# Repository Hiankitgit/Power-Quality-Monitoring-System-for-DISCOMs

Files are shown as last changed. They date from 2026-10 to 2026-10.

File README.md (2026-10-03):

# Power Quality Monitoring System for DISCOMs

   

## 📌 Overview
A low-cost, embedded diagnostic node designed for electricity distribution networks (DISCOMs). This system is engineered to detect sub-threshold power quality anomalies that are typically invisible to conventional protection devices. 

The hardware acts as a unified motherboard, integrating microcontrollers, analog voltage sensing, and industrial RS-485 communication into a single robust node.

## 🔌 Hardware Architecture
The custom PCB functions as a docking station utilizing pre-built modules and discrete through-hole components:
*   **Microcontrollers:** Arduino Uno & STM32 Blue Pill
*   **Voltage Sensing:** ZMPT101B AC voltage transformer module
*   **Communication:** MAX485 (TTL-to-RS485 transceiver) for node-level fault reporting
*   **Safety Infrastructure:** 220V AC mains are wired directly into the ZMPT module terminals, keeping high-voltage traces entirely isolated from the custom 5V logic board.

## 🛠️ PCB Design & Fabrication
Designed entirely in **KiCad**, the board layout was heavily optimized for DIY in-house manufacturing.
*   **Clearances & Traces:** Passed stringent DRC with 0.2mm minimum clearance. Main 5V and GND power rails are thickened (0.8mm) to prevent voltage drops across the docked modules.
*   **Routing Logic:** Verified intermediate node routing (including daisy-chained parallel capacitors) with 45-degree smoothed traces to prevent acid traps.
*   **Fabrication Method:** Specifically routed to support the **toner transfer etching** method on a blank copper clad board. A 1:1 scale mirrored PDF and standard Gerber `.zip` are provided in the `/fabrication` directory.

## 🖼️ Board Previews

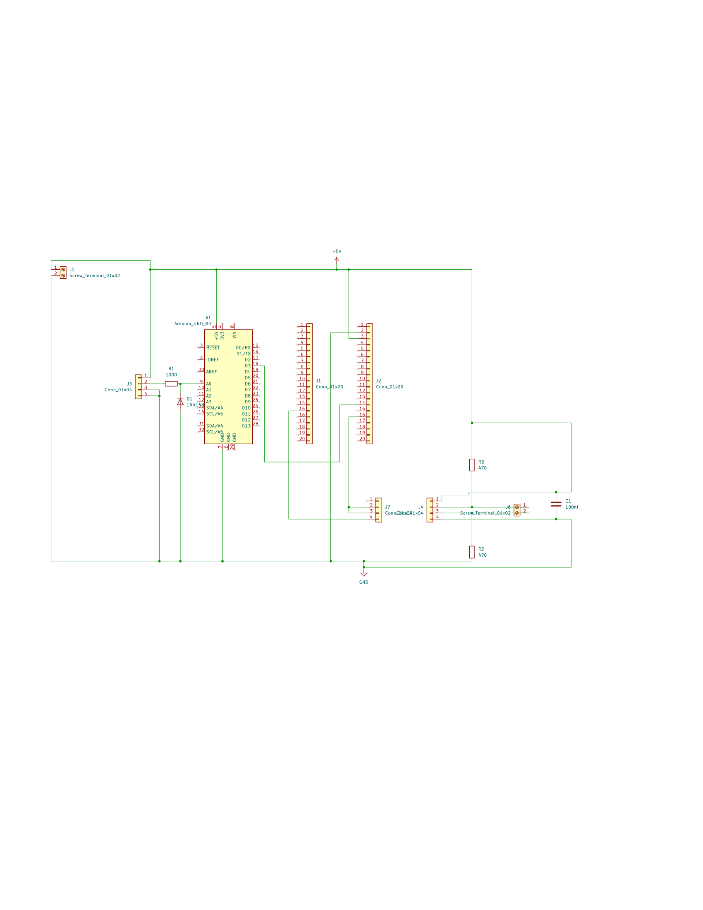
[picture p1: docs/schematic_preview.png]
Schematic Preview

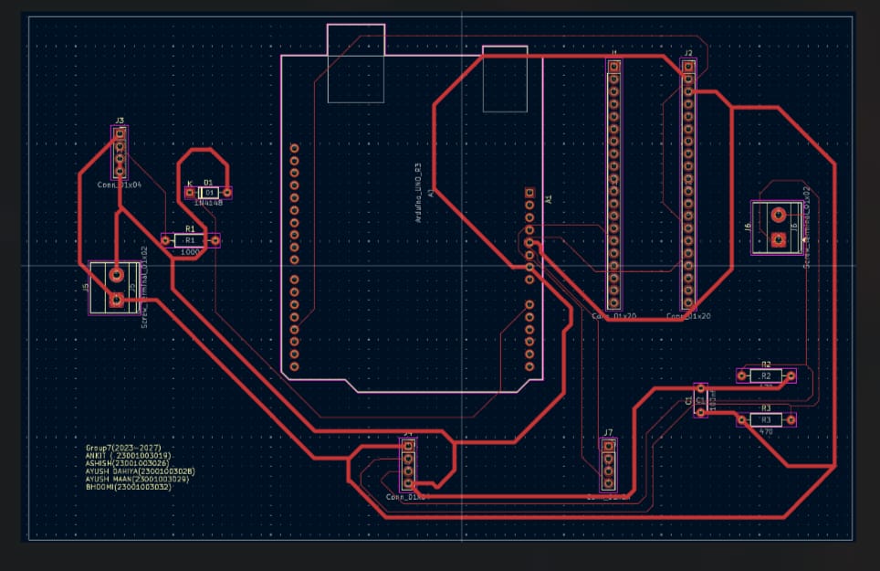
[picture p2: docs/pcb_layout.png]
PCB 2D Layout


# 💻 Firmware: Power Quality Monitoring Node

⚠️ **Status: Work In Progress (Fine-Tuning Phase)**

This directory contains the source code for the Arduino Uno and STM32 microcontrollers. 

### Current Development Focus
The baseline hardware communication is established, and we are actively calibrating the embedded signal processing algorithms. 
Current tasks include:
* Fine-tuning the ZMPT101B analog-to-digital (ADC) sampling windows.
* Implementing isolation and classification logic for 4 distinct power fault types.
* Formatting the RS-485 serial packet structure for reliable data transmission to DISCOMs.

Code will be updated regularly as the fault classification algorithms are finalized.

## 👥 Team & Credits
This system is being developed as an undergraduate academic group project by ECE Group 7 (2023–2027) under the supervision of Dr. Prachi Choudhary[cite: 8].

*   **Ankit** (23001003019) – Hardware Architecture & Lead PCB Design[cite: 3]
*   **Ashish** (23001003026)[cite: 3]
*   **Ayush Dahiya** (23001003028)[cite: 3]
*   **Ayush Maan** (23001003029)[cite: 3]
*   **Bhoomi** (23001003032)[cite: 3]

---
*Note: This repository contains the complete KiCad project files (`.kicad_pro`, `.kicad_sch`, `.kicad_pcb`), manufacturing drill/Gerber files, and firmware source code.*

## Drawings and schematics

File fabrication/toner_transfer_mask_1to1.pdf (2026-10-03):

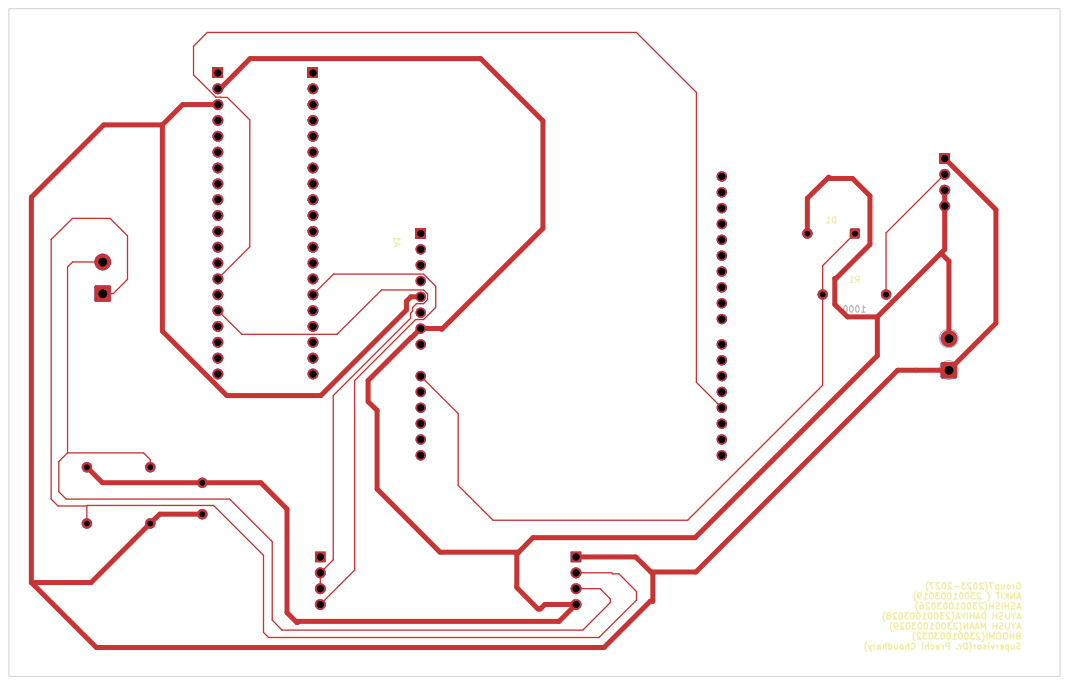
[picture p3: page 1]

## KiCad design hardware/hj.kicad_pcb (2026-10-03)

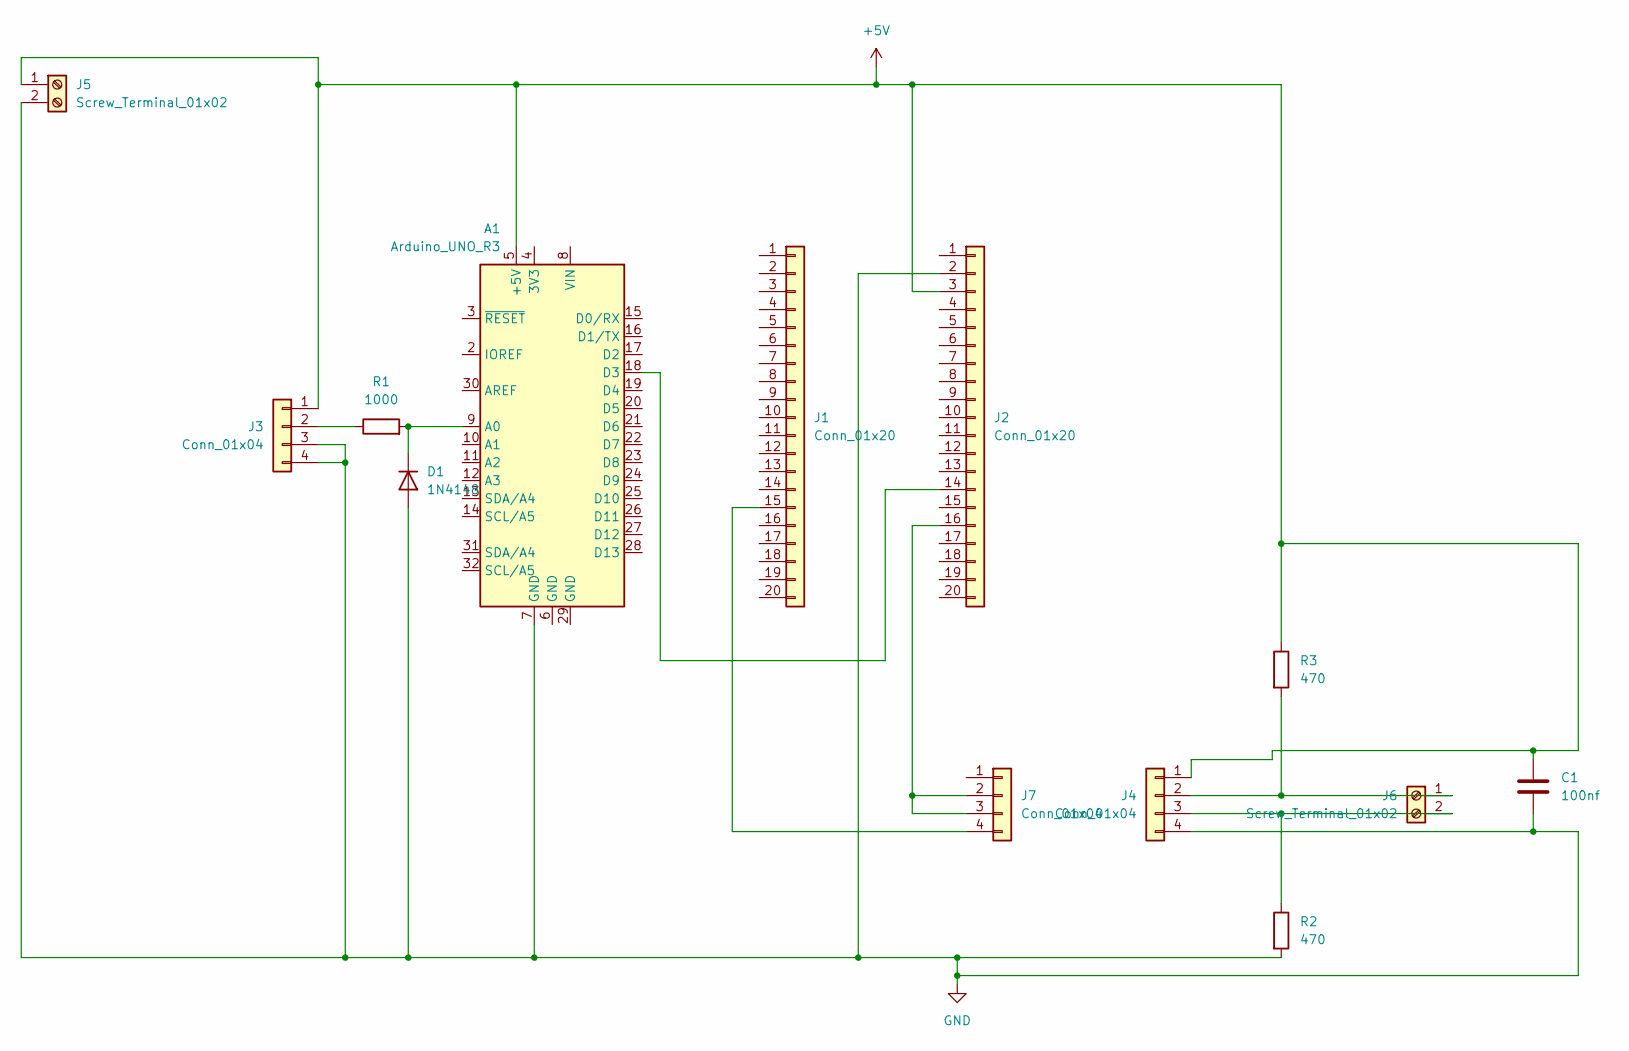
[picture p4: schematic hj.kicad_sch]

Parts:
A1: Arduino_UNO_R3
C1: 100nf; C_Disc_D5.0mm_W2.5mm_P5.00mm
D1: 1N4148; D_DO-35_SOD27_P7.62mm_Horizontal
J1, J2: Conn_01x20; PinSocket_1x20_P2.54mm_Vertical
J3, J4, J7: Conn_01x04; PinSocket_1x04_P2.54mm_Vertical
J5, J6: Screw_Terminal_01x02; TerminalBlock_Phoenix_MKDS-1,5-2-5.08_1x02_P5.08mm_Horizont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
R1: 1000; R_Axial_DIN0207_L6.3mm_D2.5mm_P10.16mm_Horizontal
R2, R3: 470; R_Axial_DIN0207_L6.3mm_D2.5mm_P10.16mm_Horizontal

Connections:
+5V: A1.5 (+5V), C1.1, J2.3, J3.1, J4.1, J5.1, R3.1
GND: A1.7 (GND), C1.2, D1.2 (A), J2.2, J3.3, J3.4, J4.4, J5.2, R2.2
unnamed: A1.9 (A0), D1.1 (K), R1.2
unnamed: A1.18 (D3), J2.14
unnamed: J1.15, J7.4
unnamed: J2.16, J7.2, J7.3
unnamed: J3.2, R1.1
unnamed: J4.2, J6.1, R3.2
unnamed: J4.3, J6.2, R2.1

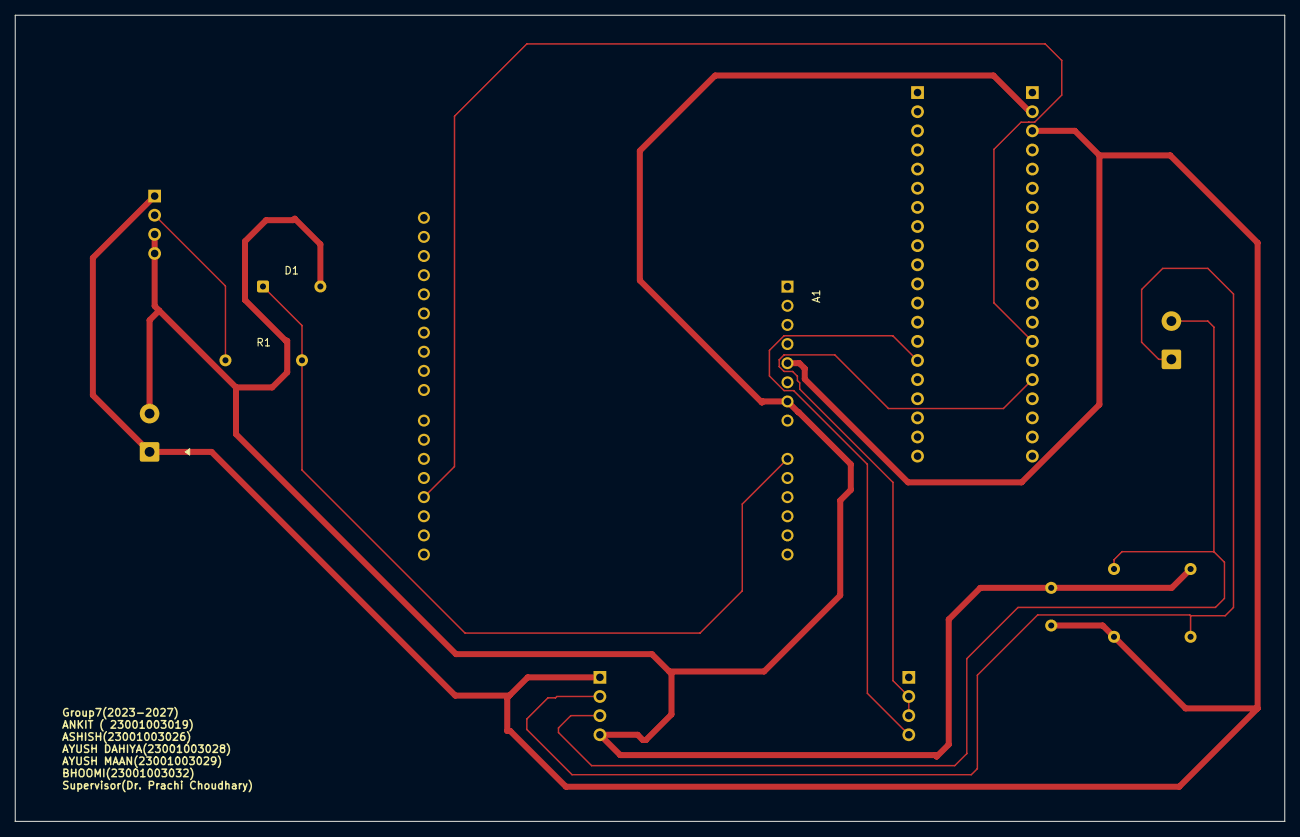
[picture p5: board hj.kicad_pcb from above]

Board: 2 copper layers, 168.5 x 107.0 mm, 13 parts (0 on the bottom side), 9 nets.

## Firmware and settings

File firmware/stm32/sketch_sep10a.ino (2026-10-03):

// ============================================================
//  POWER QUALITY MONITOR — STM32 Blue Pill Classifier
//  DCRUST BTech Project | Final Tuned Version (2V Sag Drop)
// ============================================================
#include <Arduino.h>

Uart SerialUno(PA10, PA9);      
Uart SerialRS485(PB11, PB10);   

#define RS485_DE_RE PA8

float SAG_V      = 0.0f;
float SWELL_V    = 0.0f;
float CREST_MAX  = 0.0f;
long  NOISE_MED  = 0;
long  NOISE_HIGH = 0;
const int ZC_NORMAL = 2;
const int MAX_PER_CLASS = 5;

// --- Auto-Calibration Variables ---
bool isCalibrated = false;
int  calibCount = 0;
float sumRms = 0;
float sumCf = 0;
long  sumNoise = 0;
const int REQUIRED_CALIB_SAMPLES = 100; 

int tappingCounter = 0; 

unsigned long lastHeartbeatMs = 0;
const unsigned long HEARTBEAT_MS = 10000UL;

struct Features {
  float rms; float peak; int zeroCross; long noiseEnergy; float crestFactor;
};

struct Scores {
  int tap; int loose; int overload; int degrade;
};

static uint8_t xorChecksum(const char* s) {
  uint8_t crc = 0;
  while (*s) crc ^= (uint8_t)(*s++);
  return crc;
}

static bool parsePacket(const char* raw, Features* f) {
  if (!raw || raw[0] != 'F' || raw[1] != ':') return false;
  int rmsInt = 0, peakInt = 0, cfInt = 0, zc = 0;
  long noise = 0;
  int parsed = sscanf(raw + 2, "%d,%d,%d,%ld,%d", &rmsInt, &peakInt, &zc, &noise, &cfInt);
  if (parsed != 5) return false;
  
  f->rms         = rmsInt  / 10.0f;
  f->peak        = peakInt / 10.0f;
  f->zeroCross   = zc;
  f->noiseEnergy = noise;
  f->crestFactor = cfInt   / 100.0f;
  
  if (f->rms < 50.0f || f->rms > 400.0f) return false;
  return true;
}

static void transmitRS485(const char* packet) {
  digitalWrite(RS485_DE_RE, HIGH);
  delay(1);
  SerialRS485.print(packet);
  SerialRS485.flush();
  delay(2);
  digitalWrite(RS485_DE_RE, LOW);
}

static Scores computeScores(const Features& f) {
  Scores s = {0, 0, 0, 0};

  if (f.noiseEnergy > NOISE_MED || f.rms < SAG_V) {
    if (f.noiseEnergy > NOISE_MED) {
      tappingCounter += 3; 
    } else {
      if (tappingCounter > 0) tappingCounter--; 
    }
    
    if (tappingCounter > 15) tappingCounter = 15; 

    if (tappingCounter >= 4) { 
        s.tap = 5; 
    } else if (f.rms < SAG_V) {
        s.overload = 5; 
    }
    return s;
  } else {
    tappingCounter = 0; 
  }

  if (f.noiseEnergy > NOISE_HIGH && f.zeroCross != ZC_NORMAL) {
    s.loose = 5; 
  } else if (f.crestFactor >= CREST_MAX) {
    s.degrade = 5; 
  }

  return s;
}

static void processEvent(const Features& f) {
  // If mains drops completely, force STM32 back to learning mode
  if (f.rms < 80.0f) {
    isCalibrated = false;
    calibCount = 0;
    sumRms = 0;
    sumCf = 0;
    sumNoise = 0;
    transmitRS485("\r\n[RESET] Mains lost. Re-entering calibration mode...\r\n");
    return;
  }

  bool healthy = (f.rms >= SAG_V && f.rms <= SWELL_V && 
                  f.zeroCross == ZC_NORMAL && 
                  f.crestFactor < CREST_MAX && 
                  f.noiseEnergy < NOISE_MED);
  if (healthy) {
      tappingCounter = 0; 
      return; 
  }

  Scores s = computeScores(f);
  int maxScore = max(max(s.tap, s.loose), max(s.overload, s.degrade));

  const char* type = "UNKNOWN";
  if (s.tap >= 3)          type = "TAPPING";
  else if (s.overload >= 3)type = "OVERLOAD";
  else if (s.loose >= 3)   type = "LOOSE_JOINT";
  else if (s.degrade >= 3) type = "DEGRADATION";

  int rms_i  = (int)f.rms;           int rms_d  = abs((int)(f.rms * 10) % 10);
  int pk_i   = (int)f.peak;          int pk_d   = abs((int)(f.peak * 10) % 10);
  int cf_i   = (int)f.crestFactor;   int cf_d   = abs((int)(f.crestFactor * 100) % 100);

  float conf = (float)maxScore / (float)MAX_PER_CLASS;
  if (conf > 1.0f) conf = 1.0f;
  int conf_i = (int)conf; int conf_d = abs((int)(conf * 100) % 100);

  char dsid[64];
  snprintf(dsid, sizeof(dsid), "%d.%d|%d.%d|%d|%ld|%d.%02d",
           rms_i, rms_d, pk_i, pk_d, f.zeroCross, f.noiseEnergy, cf_i, cf_d);

  char body[220];
  snprintf(body, sizeof(body),
           "NODE=N1,TIME=%lu,TYPE=%s,CONF=%d.%02d,TAP=%d,LOOSE=%d,OVR=%d,DEG=%d,DSID=%s",
           millis(), type, conf_i, conf_d, s.tap, s.loose, s.overload, s.degrade, dsid);

  uint8_t crc = xorChecksum(body);
  char full[260];
  snprintf(full, sizeof(full), "%s*%02X\r\n", body, crc);
  transmitRS485(full);
}

void setup() {
  pinMode(RS485_DE_RE, OUTPUT);
  digitalWrite(RS485_DE_RE, LOW);
  SerialUno.begin(19200);   
  SerialRS485.begin(115200);
  delay(1500);
  
  while(SerialUno.available()) SerialUno.read();

  isCalibrated = false; // Force calibration on every boot
  transmitRS485("\r\nSYSTEM BOOT: Learning grid baseline for 3 seconds...\r\n");
}

void loop() {
  if (!isCalibrated) {
    if (SerialUno.available()) {
      char buf[64];
      int len = SerialUno.readBytesUntil('\n', buf, sizeof(buf) - 1);
      buf[len] = '\0';
      Features f;
      if (parsePacket(buf, &f)) {
        if (f.rms < 80.0f) return;

        sumRms += f.rms;
        sumCf += f.crestFactor;
        sumNoise += f.noiseEnergy;
        calibCount++;

        if (calibCount >= REQUIRED_CALIB_SAMPLES) {
          float baseRms = sumRms / REQUIRED_CALIB_SAMPLES;
          float baseCf = sumCf / REQUIRED_CALIB_SAMPLES;
          long baseNoise = sumNoise / REQUIRED_CALIB_SAMPLES;

          // TUNED FOR 800W IRON: Exactly 2V drop threshold
          SAG_V      = baseRms - 4.0f;    
          SWELL_V    = baseRms + 15.0f;   
          CREST_MAX  = baseCf + 0.08f;    
          NOISE_MED  = baseNoise + 300L;  
          NOISE_HIGH = baseNoise * 3;     

          char calMsg[150];
          int rms_i = (int)baseRms; int rms_d = abs((int)(baseRms * 10) % 10);
          int sag_i = (int)SAG_V;   int sag_d = abs((int)(SAG_V * 10) % 10);
          
          snprintf(calMsg, sizeof(calMsg), 
            "[CALIBRATED] Base RMS:%d.%dV | Sag Limit:%d.%dV | Base Noise:%ld\r\n", 
            rms_i, rms_d, sag_i, sag_d, baseNoise);
            
          transmitRS485(calMsg);
          isCalibrated = true;
        }
      }
    }
    return; 
  }

  if (millis() - lastHeartbeatMs >= HEARTBEAT_MS) {
    char body[96];
    snprintf(body, sizeof(body), "NODE=N1,TIME=%lu,TYPE=HEARTBEAT,CONF=1.00,DSID=0|0|0|0|0", millis());
    uint8_t crc = xorChecksum(body);
    char full[120];
    snprintf(full, sizeof(full), "%s*%02X\r\n", body, crc);
    transmitRS485(full);
    lastHeartbeatMs = millis();
  }

  if (SerialUno.available()) {
    char buf[64];
    int len = SerialUno.readBytesUntil('\n', buf, sizeof(buf) - 1);
    buf[len] = '\0';
    Features f;
    if (parsePacket(buf, &f)) {
      processEvent(f);
    }
  }
}

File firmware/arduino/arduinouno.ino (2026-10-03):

// ============================================================
//  POWER QUALITY MONITOR — Arduino Uno Sampler
//  DCRUST BTech Project | Restored Full Debug Prints
// ============================================================

#include <SoftwareSerial.h>

#define ADC_PIN      A0
#define SS_TX_PIN     3
#define SS_RX_PIN     4
#define LED_PIN      13

#define NUM_SAMPLES         192
#define SAMPLE_INTERVAL_US  104

#define ACTUAL_MAINS_V  230.0f

float voltageScale = 1.0f;
int   dcBias       = 512;

SoftwareSerial stmSerial(SS_RX_PIN, SS_TX_PIN);

bool calibrate() {
  long biasSum = 0;
  for (int i = 0; i < 500; i++) {
    biasSum += analogRead(ADC_PIN);
    delayMicroseconds(50);
  }
  dcBias = (int)(biasSum / 500L);

  long calSumSq   = 0L;
  int calSamples  = NUM_SAMPLES * 2;
  for (int i = 0; i < calSamples; i++) {
    unsigned long slotStart = micros();
    int unbiased = analogRead(ADC_PIN) - dcBias;
    calSumSq += (long)unbiased * unbiased;
    while ((micros() - slotStart) < (unsigned long)SAMPLE_INTERVAL_US);
  }
  float rawRMS = sqrt((float)calSumSq / (float)calSamples);
  
  if (rawRMS < 80.0f) {  
    return false; 
  }

  voltageScale = ACTUAL_MAINS_V / rawRMS;
  Serial.println("[CAL] Calibration successful.");
  Serial.print("[CAL] bias=");  Serial.print(dcBias);
  Serial.print("  rawRMS=");    Serial.print(rawRMS, 2);
  Serial.print("  scale=");     Serial.println(voltageScale, 4);
  return true;
}

void setup() {
  Serial.begin(115200);
  stmSerial.begin(19200);

  ADCSRA &= ~(bit(ADPS2) | bit(ADPS1) | bit(ADPS0));
  ADCSRA |=   bit(ADPS2) | bit(ADPS0);

  Serial.println("[INIT] Waiting for stable mains power...");
  while (!calibrate()) {
    delay(1000); 
  }
  Serial.println("[INIT] Sampling started.");
  pinMode(LED_PIN, OUTPUT);
}

void loop() {
  {
    int prev = analogRead(ADC_PIN) - dcBias;
    unsigned long syncStart = millis();
    while (true) {
      int curr = analogRead(ADC_PIN) - dcBias;
      if (prev < -3 && curr >= -3) break;
      prev = curr;
      if (millis() - syncStart > 100UL) break;
    }
  }

  long sumSq        = 0L;
  int  maxPeak      = 0;
  int  zcCount      = 0;
  long noiseEnergy  = 0L;
  int  lastUnbiased = 0;
  int  lastSign     = 0;

  for (int i = 0; i < NUM_SAMPLES; i++) {
    unsigned long slotStart = micros();

    int rawVal   = analogRead(ADC_PIN);
    int unbiased = rawVal - dcBias;

    sumSq += (long)unbiased * unbiased;

    int absVal = abs(unbiased);
    if (absVal > maxPeak) maxPeak = absVal;

    if (i > 0) noiseEnergy += (long)abs(unbiased - lastUnbiased);
    lastUnbiased = unbiased;

    int currentSign = 0;
    if      (unbiased >  3) currentSign =  1;
    else if (unbiased < -3) currentSign = -1;
    if (lastSign != 0 && currentSign != 0 && currentSign != lastSign) zcCount++;
    if (currentSign != 0) lastSign = currentSign;

    while ((micros() - slotStart) < (unsigned long)SAMPLE_INTERVAL_US);
  }

  float rmsADC      = sqrt((float)sumSq / (float)NUM_SAMPLES);
  float realRMS     = rmsADC * voltageScale;
  float realPeak    = (float)maxPeak * voltageScale;
  float crestFactor = (rmsADC > 1.0f) ? ((float)maxPeak / rmsADC) : 0.0f;

  if (realRMS < 80.0f || realRMS > 350.0f) {
    delay(1000); 
    while(!calibrate()) { delay(1000); }
    return;
  }

  // --- RESTORED LOCAL SERIAL MONITOR PRINTS ---
  Serial.print("RMS=");         Serial.print(realRMS, 1);
  Serial.print("V Peak=");      Serial.print(realPeak, 1);
  Serial.print("V ZC=");        Serial.print(zcCount);
  Serial.print(" Noise=");      Serial.print(noiseEnergy);
  Serial.print(" CF=");         Serial.print(crestFactor, 3);
  Serial.print(" RAW_ADC_RMS=");Serial.print(rmsADC, 2);
  Serial.print(" BIAS=");       Serial.println(dcBias);

  int rmsInt  = (int)(realRMS     * 10.0f + 0.5f);
  int peakInt = (int)(realPeak    * 10.0f + 0.5f);
  int cfInt   = (int)(crestFactor * 100.0f + 0.5f);

  char txBuf[40];
  snprintf(txBuf, sizeof(txBuf), "F:%d,%d,%d,%ld,%d\n",
           rmsInt, peakInt, zcCount, noiseEnergy, cfInt);
  stmSerial.print(txBuf);

  digitalWrite(LED_PIN, !digitalRead(LED_PIN));
}
